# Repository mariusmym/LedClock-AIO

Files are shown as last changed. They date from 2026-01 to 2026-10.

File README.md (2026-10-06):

# LedClock-AIO (All In One)

LED Clock

   

A **~100x33mm** version of the **[ledclock](https://github.com/imeszaros/ledclock)** project by [imeszaros](https://github.com/imeszaros), powered by [WLED](https://github.com/wled/WLED). 

It tells the time, it changes colors, and it never asks you to update it at 3 AM. Well ... almost never.

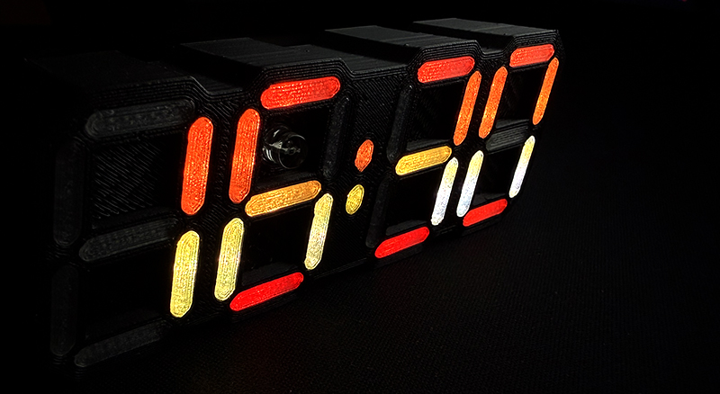
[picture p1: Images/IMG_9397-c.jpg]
IMG_9397-c


## Description and features 

This version takes an **ALL IN ONE** (AIO) approach to the **[ledclock](https://github.com/imeszaros/ledclock)** project: one PCB, no extra modules, no wires hiding inside the case.

- **99.74x33.2mm PCB** - deliberately kept under 100mm, because PCB fabs charge extra for every millimeter past that, and that money is better spent on filament.
- **USB-C powered** - one cable and you're done. No barrel jacks, no mystery power bricks from the drawer.
- **Hand-solderable** - some footprints were modified specifically to make hand soldering possible.

That said, I still strongly recommend **ordering a stencil**, at least for the FRONT of the PCB (where the LEDs are). Hand soldering all those LEDs one by one is technically possible (the same way walking to the seaside is technically possible).

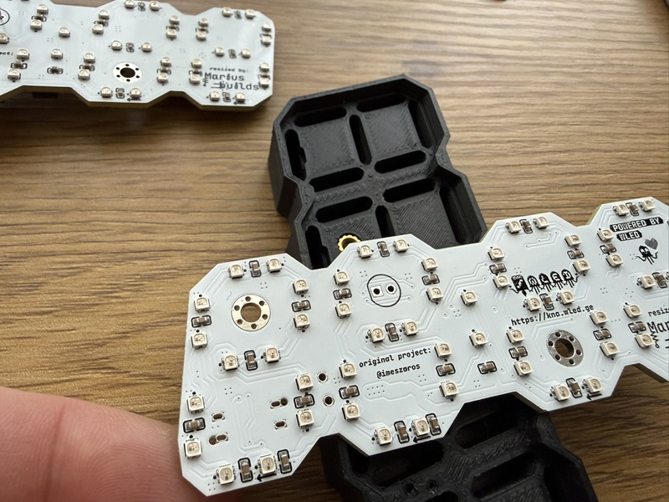
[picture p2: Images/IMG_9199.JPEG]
leds


The **schematic** also includes some cheaper alternatives for the photosensitive sensor and the potentiometer. You can find them on [lcsc.com](https://www.lcsc.com/) by searching the part number listed below each one (e.g. C242253 for the photosensitive sensor alternative). **The alternative parts are not included in the BOM, to avoid confusion.** One BOM, one truth.

## LEDs alternatives 

You can also use [WS2812B-2020](https://www.lcsc.com/product-detail/C965555.html) LEDs (a bit more expensive) or [TCWIN TX1812ZN](https://www.lcsc.com/product-detail/C784563.html) (a little bit bigger). Keep in mind that you have to **double/triple check the pin orientation**, since the silkscreen marks don't match. Soldering 50+ LEDs backwards is a lesson you only want to learn once.

## Assembly instructions and tips

After finishing the top side, move on to the bottom side, and pay special attention to these two parts:

- **The photoresistive sensor** must be soldered **5–7 mm above the top layer of the PCB**, so it sticks out through the case. Otherwise your clock will think it's permanently night and dim itself into depression.

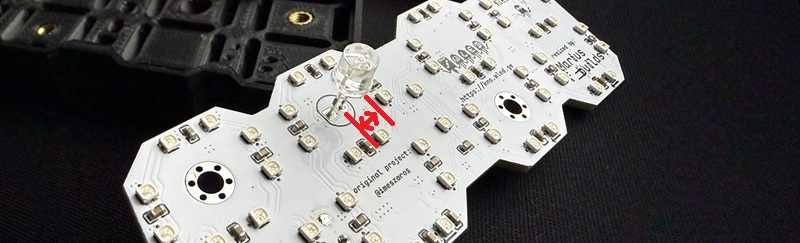
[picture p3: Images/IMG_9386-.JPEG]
distance

  
- **The C3 capacitor (1000 µF)** must be **mounted horizontally**, as shown in the image below. Standing up, it won't fit in the case, no matter how hard you push (please don't push).

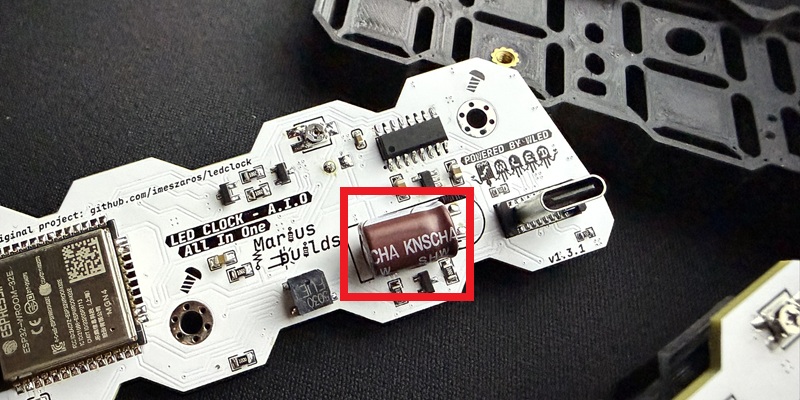
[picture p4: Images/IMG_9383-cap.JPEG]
capacitor


## Case 

Print the case files from the **CaseModel** folder of this repository in whatever colors you like. The files are also available on Printables: https://www.printables.com/model/1087560-led-clock-all-in-one-pcb-powered-by-wled

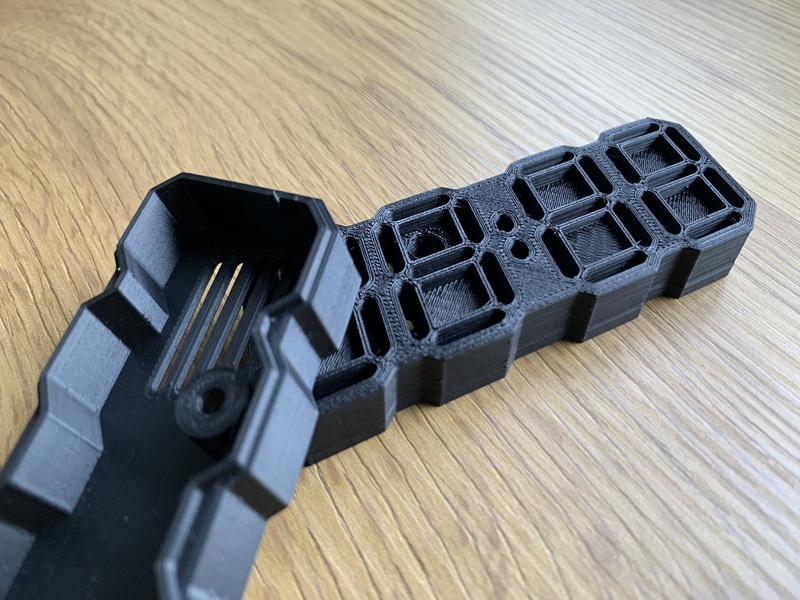
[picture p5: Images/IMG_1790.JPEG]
case1


You will also need **two M3 heat inserts** and **two M3x8mm countersunk screws**.

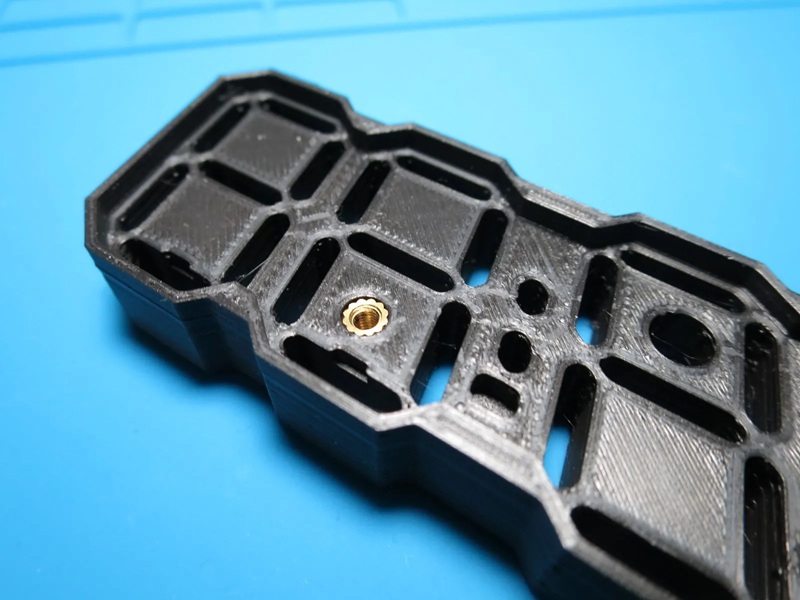
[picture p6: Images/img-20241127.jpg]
heatinsert


The segment covers need to be printed with **transparent filament, 20–30% infill and 2–3 top/bottom layers**. Depending on how accurate your printer is, you might want to print the offset segments file instead (0.1mm smaller), because not all printers are created equal and some are more "creative" than others.

**Pro tip:** to keep track of them, put masking tape over the segments before removing them from the build plate, then put a piece of kitchen stretch film over the tape. Otherwise you'll spend the next hour playing a very boring puzzle game.

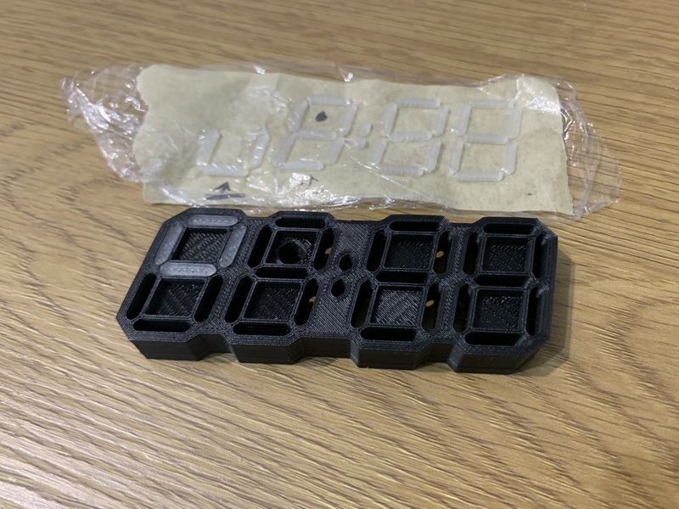
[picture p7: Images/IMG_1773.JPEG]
segments cover


If the tolerances are too tight and the segment covers won't go in, a small hammer and some gentle "tapping" will convince them :)). Gentle being the key word here: we're assembling a clock, not building a deck.

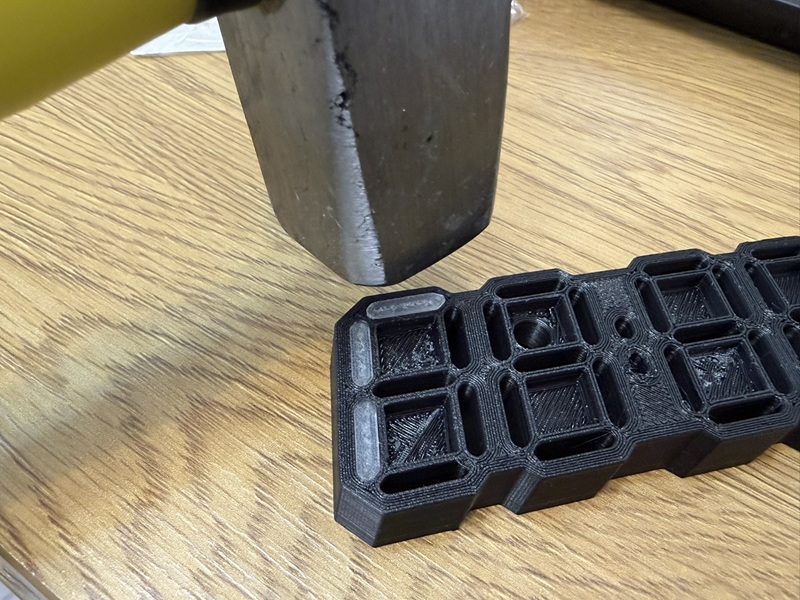
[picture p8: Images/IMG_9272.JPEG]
hammer
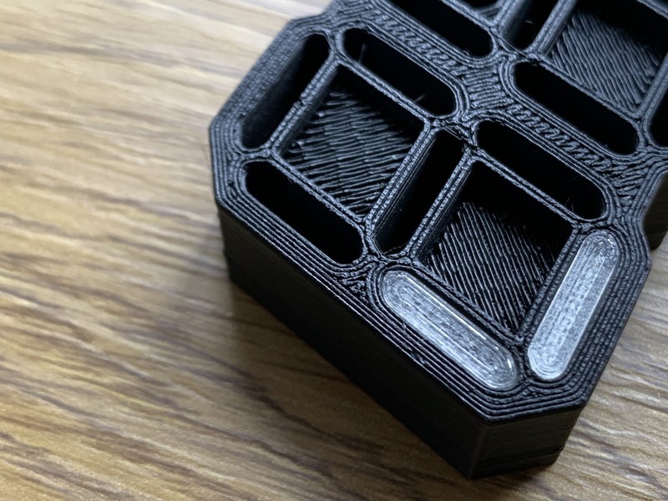
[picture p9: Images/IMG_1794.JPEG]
segments in place
 

## Firmware 

The firmware comes from the awesome work of [imeszaros](https://github.com/imeszaros), so all the credit for the smart part goes to him.

1. **Install the CH340 drivers** BEFORE connecting the clock, otherwise your computer will politely pretend nothing is plugged in.
2. Connect the LED Clock to your computer and use [this tool](https://imeszaros.github.io/ledclock/) to flash the board (make sure you select the correct COM port).
3. Download the WLED app on your phone and connect to the clock to change the colors, effects and everything else:
   - Google Play: https://play.google.com/store/apps/details?id=ca.cgagnier.wlednativeandroid
   - Apple App Store: https://apps.apple.com/us/app/wled-native/id6446207239

A detailed user guide can be found here: https://github.com/imeszaros/ledclock/blob/main/ledclock/users-guide.md

## ENJOY ! 

Now you'll never be late again. Or... at least you'll be late in style, in 16 million colors 😎.

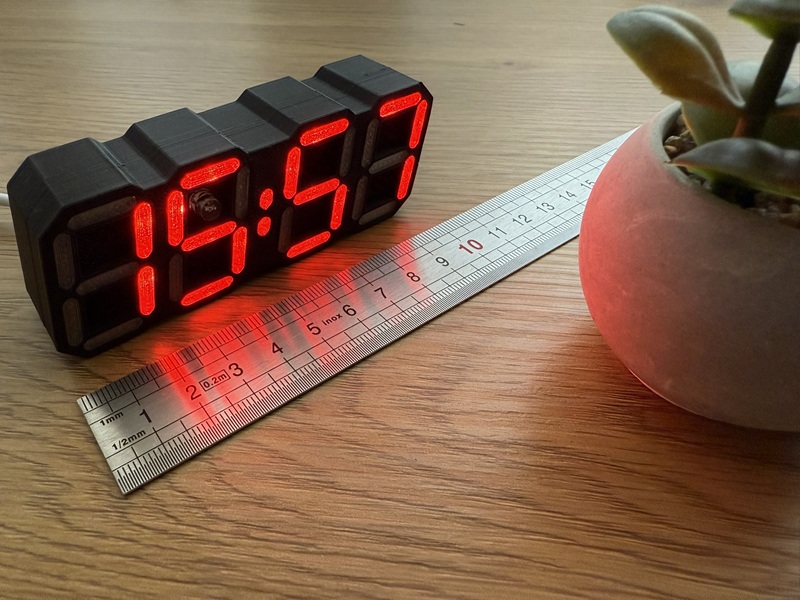
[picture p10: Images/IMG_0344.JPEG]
final picture1
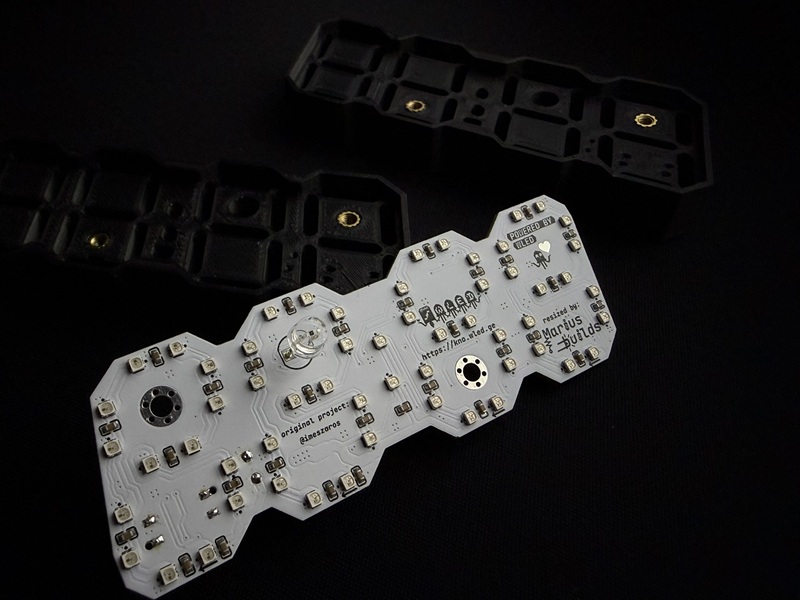
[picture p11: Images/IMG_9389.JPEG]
final picture2
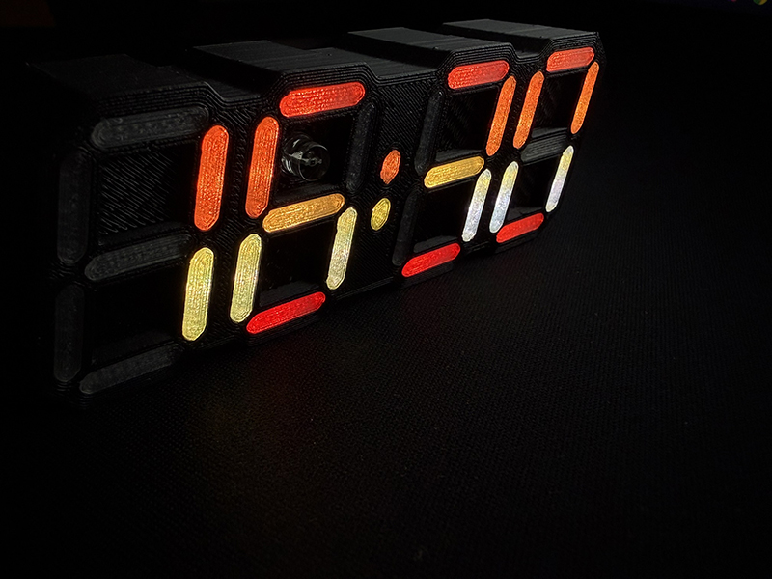
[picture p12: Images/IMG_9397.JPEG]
final picture3
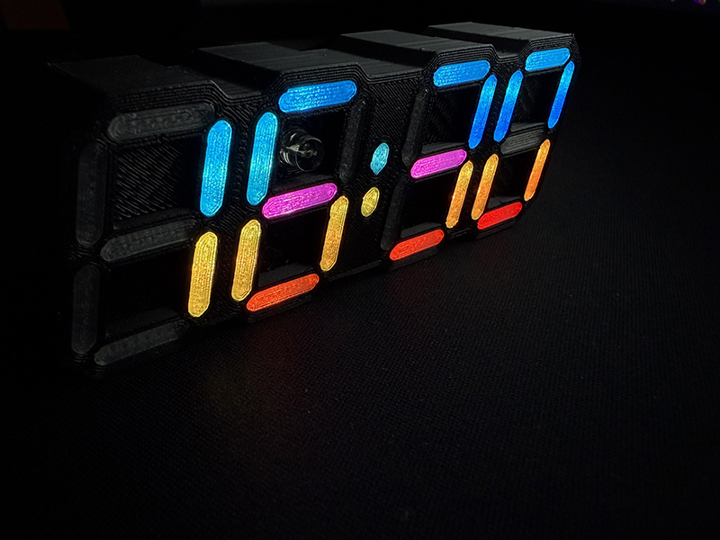
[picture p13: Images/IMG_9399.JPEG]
final picture4
   

## Donate ☕

If you'd like to say thanks or buy me a coffee, a **[PayPal donation](https://www.paypal.com/donate/?hosted_button_id=KHR7DYJP2Z8QJ)** is always appreciated!

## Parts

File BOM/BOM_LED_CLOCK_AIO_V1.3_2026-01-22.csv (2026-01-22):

ID | Name | Designator | Footprint | Quantity | Manufacturer Part | Manufacturer | Supplier | Supplier Part
1 | 10uF | C11 | C_0805 | 1 | CL21A106KAYNNNE | SAMSUNG(三星) | LCSC | C15850
2 | 100nF | C13,C9 | C_0603_S | 2 | CC0603KRX7R9BB104 | YAGEO(国巨) | LCSC | C14663
3 | 1uF | C5,C7 | C0805 | 2 | AC0805KKX7R9BB105 | YAGEO(国巨) | LCSC | C726584
4 | AP2112K-3.3TRG1 | U1 | SOT-25-5 | 1 | AP2112K-3.3TRG1 | DIODES | LCSC | C51118
5 | 1000uF | C3 | CAP-TH_BD8.0-P3.50-D0.6-FD | 1 | SHW1000UF10V8X12 | KNSCHA(科尼盛) | LCSC | C494548
6 | GT-USB-7082E | USB1 | USB-C-SMD_GT-USB-7082G | 1 | GT-USB-7082E | G-Switch(品赞) | LCSC | C22383834
7 | 4kHz | BUZZER1 | BUZ-SMD_FST-5030 | 1 | FUET-5030 | FUET(福声科技) | LCSC | C391031
8 | ESP32-WROOM-32E(4MB) | U3 | WIFI-SMD_ESP32-WROOM-32E-A-NO-PSRAM-PINS | 1 | ESP32-WROOM-32E(4MB) | Espressif Systems | LCSC | C701341
9 | 1uF | C60 | C0805 | 1 | TCC0805X7R105K500FTA | CCTC(三环) | LCSC | C282737
10 | BSS138 | Q4 | SOT-23-3_L2.9-W1.3-P1.90-LS2.4-BR | 1 | BSS138 | CJ | LCSC | C78284
11 | 100 | R1 | R0805 | 1 | AC0805FR-07100RL | YAGEO(国巨) | LCSC | C138274
12 | 10K | R2,R3,R4 | R0805 | 3 | AC0805FR-0710KL | YAGEO(国巨) | LCSC | C140868
13 | 50kΩ | R5 | RES-ADJ-SMD_3314G-1-103E | 1 | 3314G-1-503E | BOURNS | LCSC | C719184
14 | 5.1kΩ | R7,R8 | R0603 | 2 | RTT03512JTP | RALEC(旺诠) | LCSC | C103696
15 | L8050QLT1G | Q1,Q2 | SOT-23-3_L2.9-W1.3-P1.90-LS2.4-BR | 2 | L8050QLT1G | LRC | LCSC | C49581
16 | 10k | R9,R10 | R0805 | 2 | B57221V2103J060 | TDK | LCSC | C117695
17 | CH340C | U4 | CH340C | 1 | CH340C | WCH | LCSC | C84681
18 | 100nF | C1,C2,C4,C6,C8,C10,C12,C14,C18,C20,C22,C24,C26,C28,C29,C32,C34,C36,C38,C40,C42,C44,C46,C48,C50,C52,C54,C56,C58,C16,C15 | C0603 | 31 | C0603C104K5RACAUTO | KEMET(基美) | LCSC | C129621
19 | XL-1615RGBC-WS2812B | LED1,LED2,LED3,LED4,LED5,LED6,LED7,LED8,LED9,LED10,LED11,LED12,LED13,LED14,LED15,LED16,LED17,LED18,LED19,LED20,LED21,LED22,LED23,LED24,LED25,LED26,LED27,LED28,LED29,LED30,LED31,LED32,LED33,LED34,LED35,LED36,LED37,LED38,LED39,LED40,LED41,LED42,LED43,LED44,LED45,LED46,LED47,LED48,LED49,LED50,LED51,LED52,LED53,LED54,LED55,LED56,LED57,LED58 | LED-SMD_4P-L1.6-W1.5_XL-1615RGBC-WS2812B | 58 | XL-1615RGBC-WS2812B | XINGLIGHT(成兴光) | LCSC | C5349954
20 | TEPT5700 | Q3 | TEPT5700 | 1 | TEPT5700 | VISHAY | LCSC | C141763

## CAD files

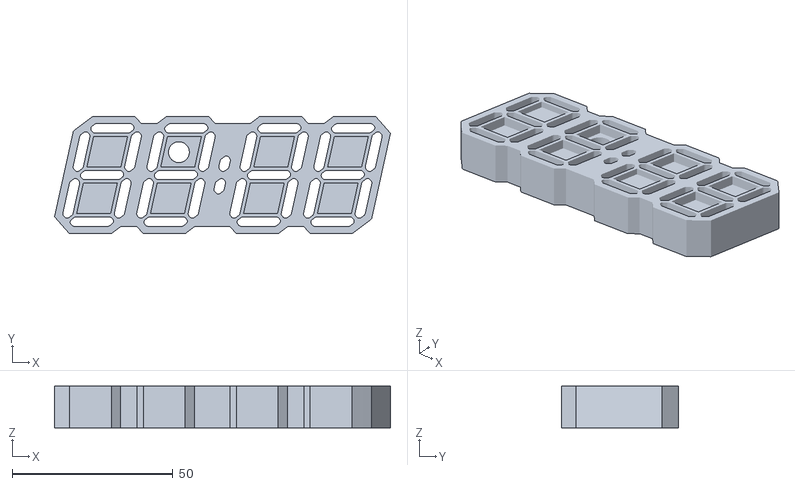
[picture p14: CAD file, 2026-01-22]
CaseModel/CASE_FLAT_FACE.stl
104.7 x 36.6 x 13.0

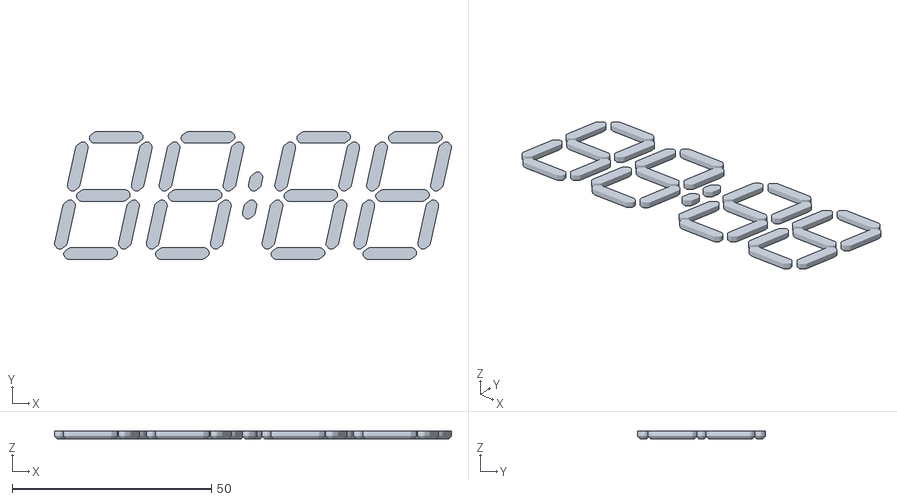
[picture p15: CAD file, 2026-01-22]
CaseModel/SEGMENT_COVER-NO-OFFEST.stl
99.5 x 32.0 x 2.00

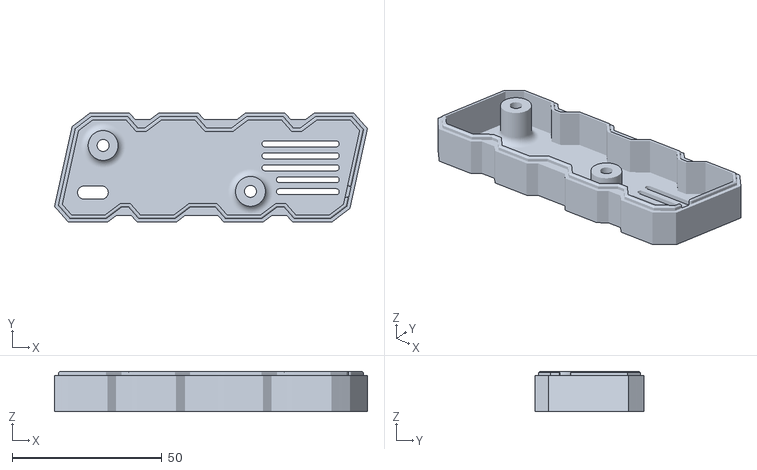
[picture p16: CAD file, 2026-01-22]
CaseModel/CASE_BACK_COVER.stl
104.7 x 36.6 x 13.4

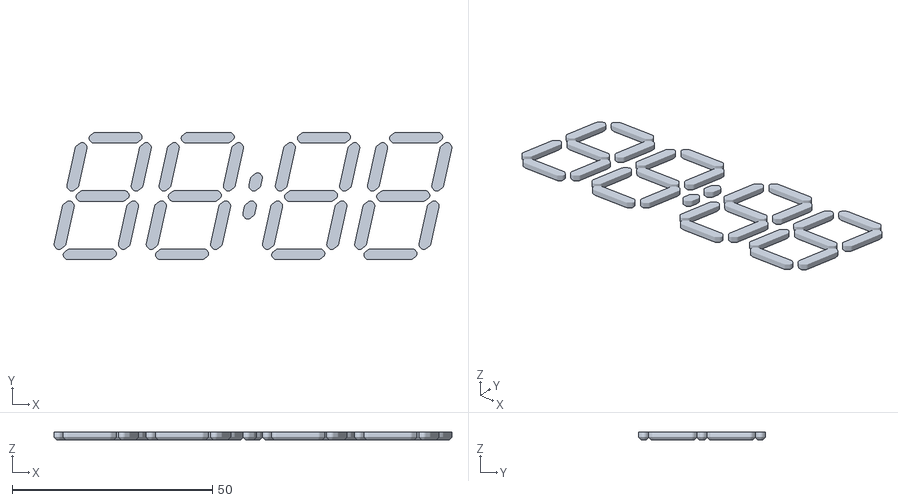
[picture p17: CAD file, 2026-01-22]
CaseModel/SEGMENT_COVER_1mm-OFFSET.stl
99.3 x 31.8 x 2.00

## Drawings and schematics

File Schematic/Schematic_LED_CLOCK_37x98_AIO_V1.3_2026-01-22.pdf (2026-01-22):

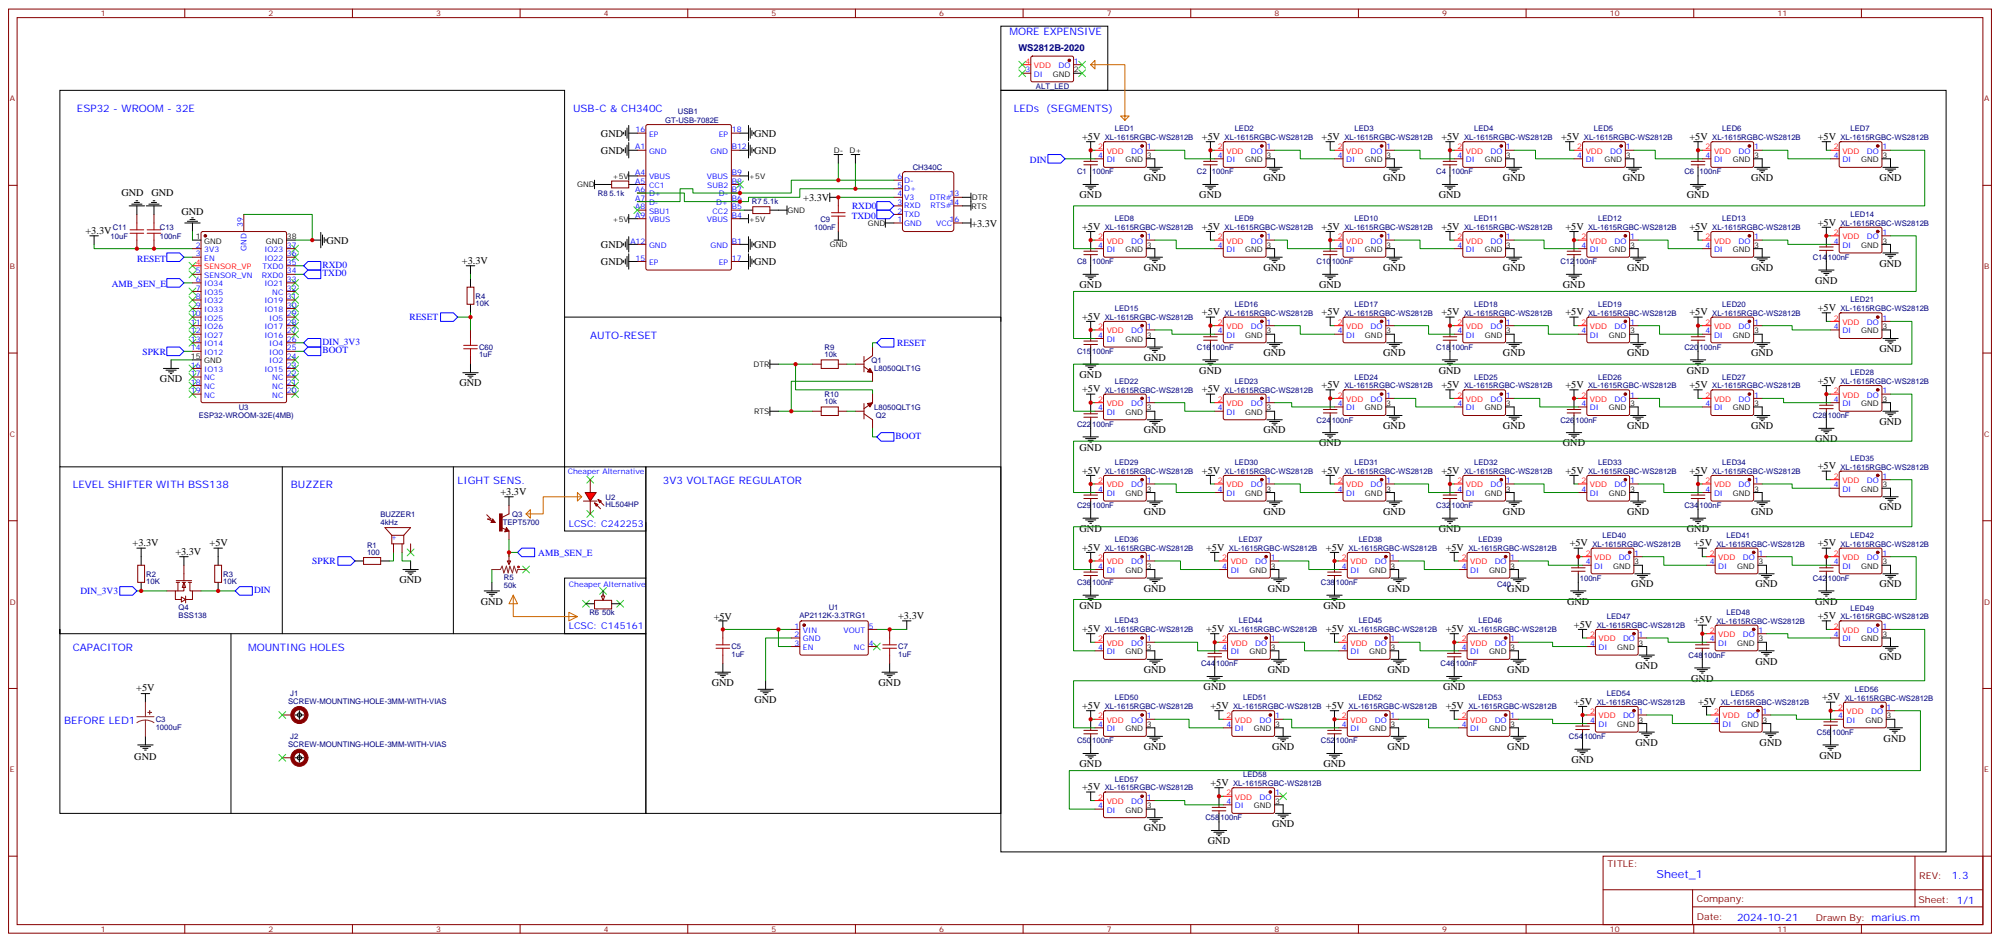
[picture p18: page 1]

SCREW-MOUNTING-HOLE-3MM-WITH-VIAS
